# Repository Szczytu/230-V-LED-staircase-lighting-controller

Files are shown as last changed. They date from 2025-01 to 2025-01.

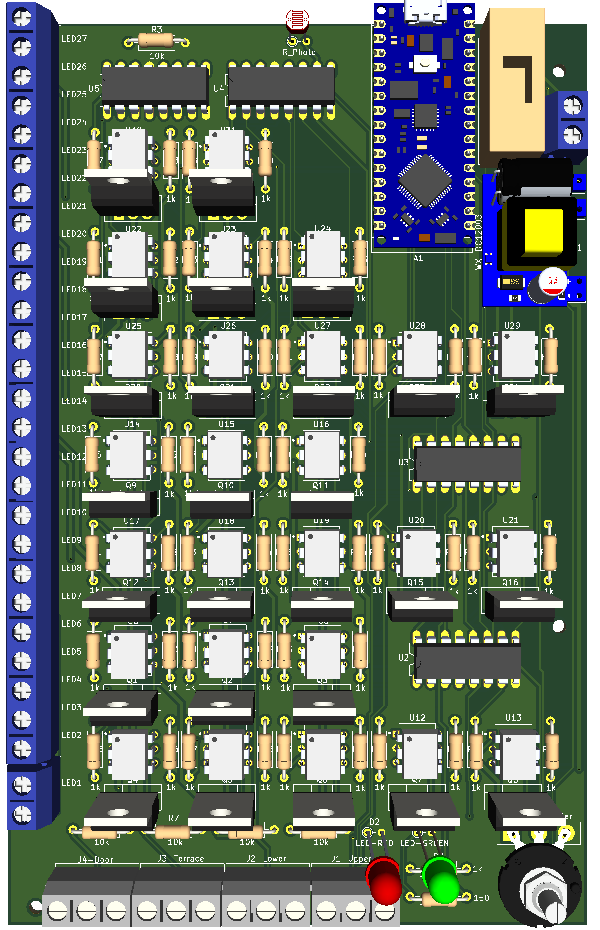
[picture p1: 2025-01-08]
PCB_162x104mm_LED_STAIRS_KiCad/CONTROLLER_LED_STAIRS_230V.png

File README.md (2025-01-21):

# 230-V-LED-staircase-lighting-controller
Controller for a large staircase consisting of 3 parts, total 26 stairs on 230 V LED strips. The controller has a built-in twilight sensor, the sensitivity of which can be adjusted using a potentiometer.
The construction of the controller was due to an unusual staircase and the desire not to use a separate power supply for 12-24V LEDs 
# Schematic and project controller of 230V LED
The project schematic, sample 3D model and gerber file is in the folder "PCB_162x104mm_LED_STAIRS"
The project was made in KiCad 8.0.
## Schematic
<p align="center">
  
</p>

## Simplified schematic
<p align="center">
  
</p>

> [!IMPORTANT]
> 1 leg of the BT136 triac is connected to the PHASE of the LED strip.
The 2nd leg of the BT136 triac is connected to the PHASE of the AC mains. The 3rd leg of the BT136 triac is connected to the gate of the power3061 controller.

> [!CAUTION]
> DO NOT SWAP THE CONNECTION FROM THE 1ST LEG WITH THE 2ND LEG OF THE BT-136 TRIAC BECAUSE IT WILL NOT WORK!

## 3D model
<p align="center">
  
  
</p>

## Final efect of the controller
A universal Kradex Z112A plastic housing with dimensions of 186x136x40mm was used to enclose the PCB
<p align="center">
  
  
  
</p>

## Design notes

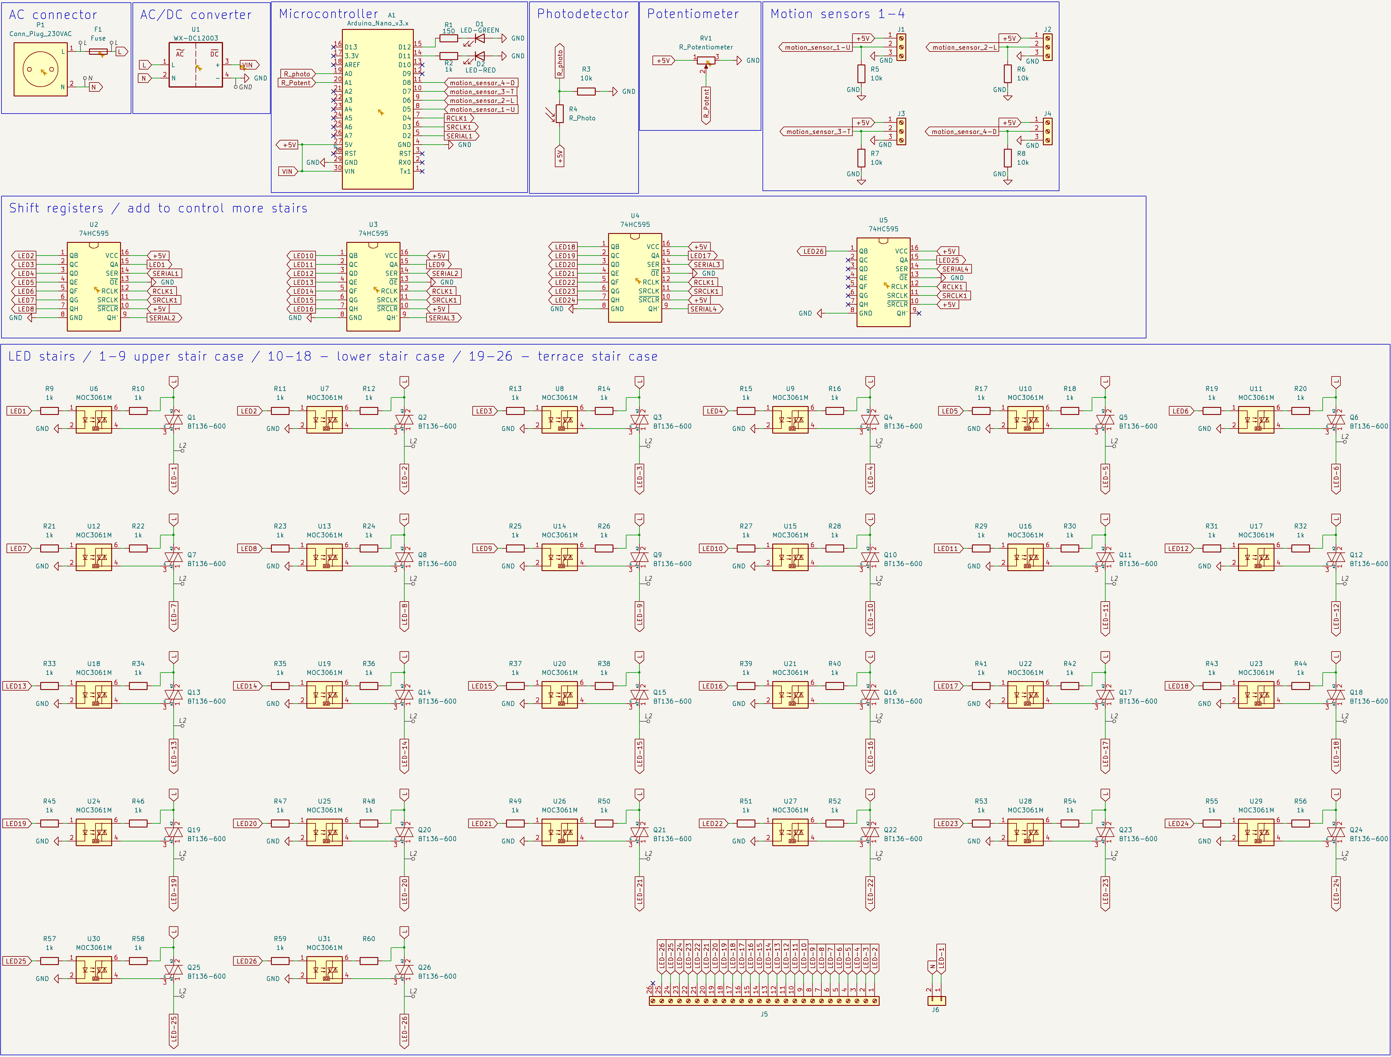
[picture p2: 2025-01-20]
PCB_162x104mm_LED_STAIRS_KiCad/CONTROLLER_LED_STAIRS_230V_schematic.png

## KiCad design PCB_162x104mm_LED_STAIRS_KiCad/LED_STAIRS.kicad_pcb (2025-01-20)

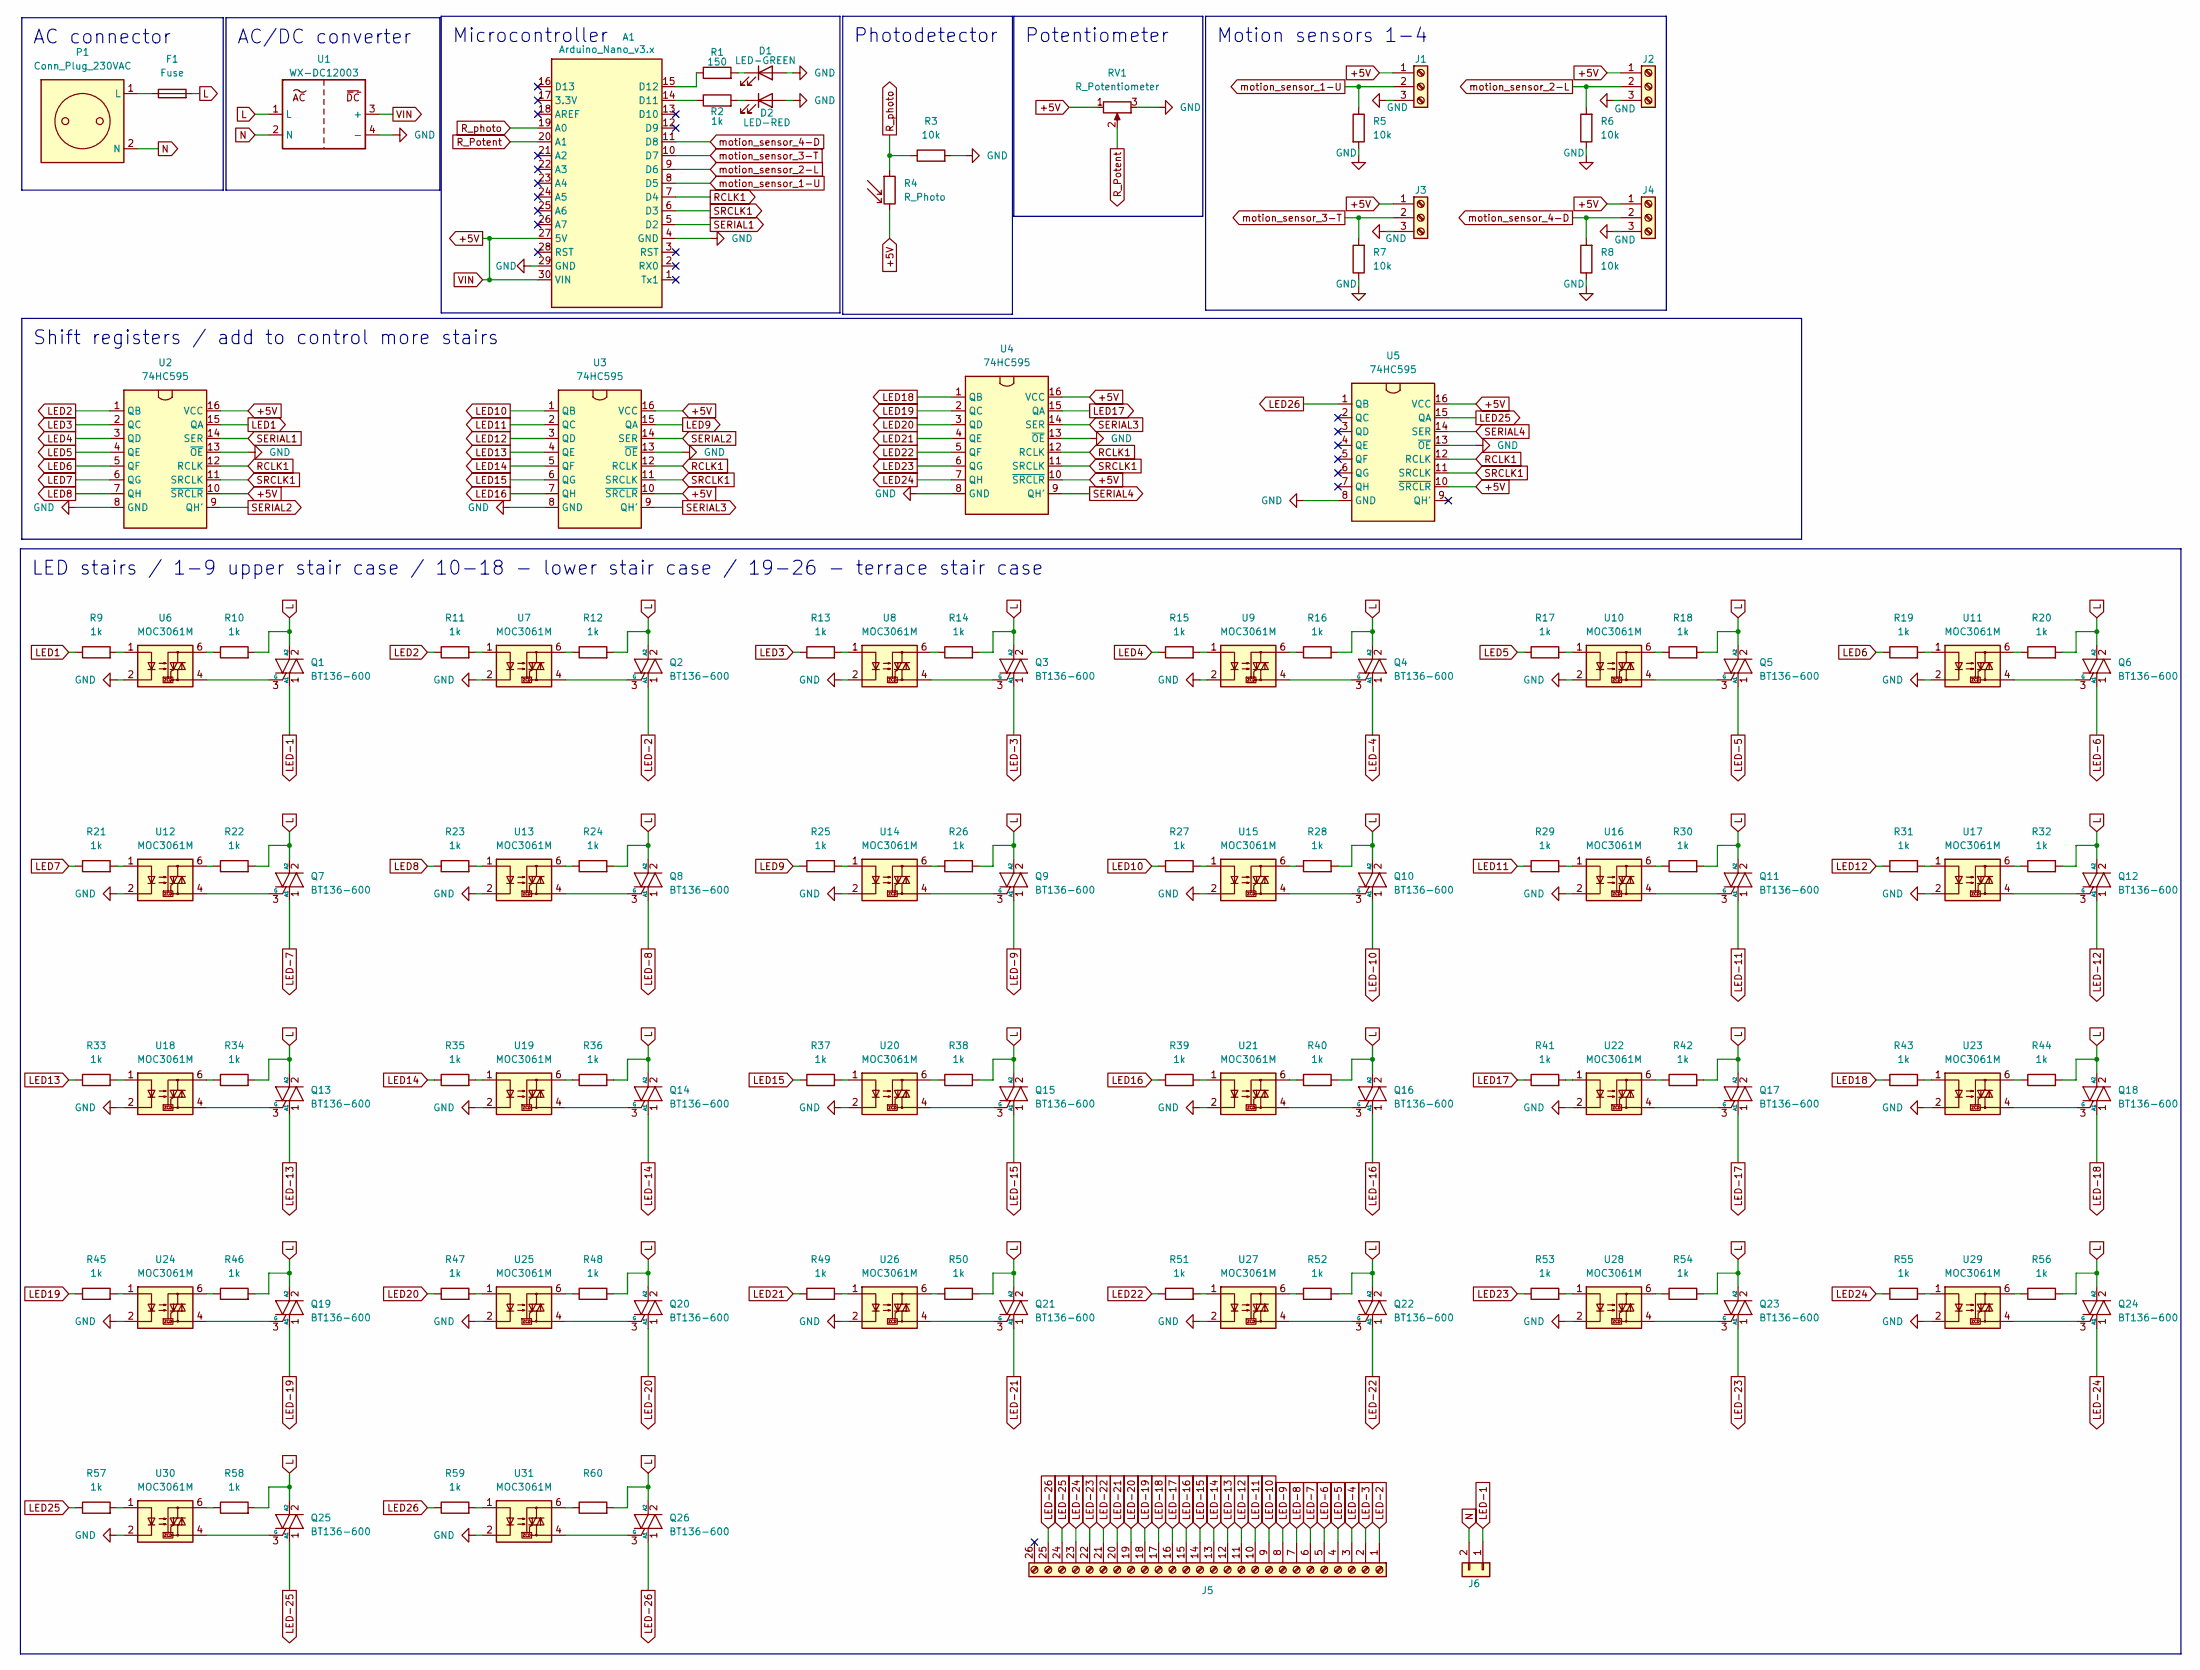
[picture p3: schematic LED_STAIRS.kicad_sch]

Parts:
A1: Arduino_Nano_v3.x; Arduino_Nano
D1: LED-GREEN; R_Axial_DIN0204_L3.6mm_D1.6mm_P2.54mm_Vertical
D2: LED-RED; R_Axial_DIN0204_L3.6mm_D1.6mm_P2.54mm_Vertical
F1: Fuse; Fuseholder_Cylinder-5x20mm_Stelvio-Kontek_PTF78_Horizontal_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
J1, J2, J3, J4: Screw_Terminal_01x03; terminalx03x2.5mmPitch
J5: Screw_Terminal_01x26; terminalx26x2.5mmPitch
J6: Conn_01x02; terminalx02x2.5mmPitch
P1: Conn_Plug_230VAC; terminalx02x2.5mmPitch
Q1, Q2, Q3, Q4, Q5, Q6, Q7, Q8, Q9, Q10, Q11, Q12, Q13, Q14, Q15, Q16, Q17, Q18, Q19, Q20, Q21, Q22, Q23, Q24, Q25, Q26: BT136-600; TO-220-3_Vertical
R1: 150; R_Axial_DIN0207_L6.3mm_D2.5mm_P10.16mm_Horizontal
R2, R9, R10, R11, R12, R13, R14, R15, R16, R17, R18, R19, R20, R21, R22, R23, R24, R25, R26, R27, R28, R29, R30, R31, R32, R33, R34, R35, R36, R37, R38, R39, R40, R41, R42, R43, R44, R45, R46, R47, R48, R49, R50, R51, R52, R53, R54, R55, R56, R57, R58, R59, R60: 1k; R_Axial_DIN0207_L6.3mm_D2.5mm_P10.16mm_Horizontal
R3, R5, R6, R7, R8: 10k; R_Axial_DIN0207_L6.3mm_D2.5mm_P10.16mm_Horizontal
R4: R_Photo; R_Axial_DIN0204_L3.6mm_D1.6mm_P2.54mm_Vertical
RV1: R_Potentiometer; Potentiometer_5k
U1: WX-DC12003
U2, U3, U4, U5: 74HC595; 74HC595N
U6, U7, U8, U9, U10, U11, U12, U13, U14, U15, U16, U17, U18, U19, U20, U21, U22, U23, U24, U25, U26, U27, U28, U29, U30, U31: MOC3061M; moc3021

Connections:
+5V: A1.27 (5V), A1.30 (VIN), J1.1, J2.1, J3.1, J4.1, R4.2, RV1.1, U1.3 (+), U2.10 (~SRCLR), U2.16 (VCC), U3.10 (~SRCLR), U3.16 (VCC), U4.10 (~SRCLR), U4.16 (VCC), U5.10 (~SRCLR), U5.16 (VCC); also elsewhere on the board
GND: A1.4 (GND), A1.29 (GND), D1.2 (A), D2.2 (A), J1.3, J2.3, J3.3, J4.3, R3.2, R5.2, R6.1, R7.1, R8.1, RV1.3, U1.4 (-), U2.8 (GND), U2.13 (~OE), U3.8 (GND), U3.13 (~OE), U4.8 (GND), U4.13 (~OE), U5.8 (GND), U5.13 (~OE), U6.2, U7.2, U8.2, U9.2, U10.2, U11.2, U12.2, U13.2, U14.2, U15.2, U16.2, U17.2, U18.2, U19.2, U20.2, U21.2, U22.2, U23.2, U24.2, U25.2, U26.2, U27.2, U28.2, U29.2, U30.2, U31.2; also elsewhere on the board
L: F1.2, Q1.2 (A2), Q2.2 (A2), Q3.2 (A2), Q4.2 (A2), Q5.2 (A2), Q6.2 (A2), Q7.2 (A2), Q8.2 (A2), Q9.2 (A2), Q10.2 (A2), Q11.2 (A2), Q12.2 (A2), Q13.2 (A2), Q14.2 (A2), Q15.2 (A2), Q16.2 (A2), Q17.2 (A2), Q18.2 (A2), Q19.2 (A2), Q20.2 (A2), Q21.2 (A2), Q22.2 (A2), Q23.2 (A2), Q24.2 (A2), Q25.2 (A2), Q26.2 (A2), R10.2, R12.2, R14.2, R16.2, R18.2, R20.2, R22.2, R24.2, R26.2, R28.2, R30.2, R32.2, R34.2, R36.2, R38.2, R40.2, R42.2, R44.2, R46.2, R48.2, R50.2, R52.2, R54.2, R56.2, R58.2, R60.2, U1.1 (L)
LED1: R9.1, U2.15 (QA)
LED2: R11.1, U2.1 (QB)
LED3: R13.1, U2.2 (QC)
LED4: R15.1, U2.3 (QD)
LED5: R17.1, U2.4 (QE)
LED6: R19.1, U2.5 (QF)
LED7: R21.1, U2.6 (QG)
LED8: R23.1, U2.7 (QH)
LED9: R25.1, U3.15 (QA)
LED10: R27.1, U3.1 (QB)
LED11: R29.1, U3.2 (QC)
LED12: R31.1, U3.3 (QD)
LED13: R33.1, U3.4 (QE)
LED14: R35.1, U3.5 (QF)
LED15: R37.1, U3.6 (QG)
LED16: R39.1, U3.7 (QH)
LED17: R41.1, U4.15 (QA)
LED18: R43.1, U4.1 (QB)
LED19: R45.1, U4.2 (QC)
LED20: R47.1, U4.3 (QD)
LED21: R49.1, U4.4 (QE)
LED22: R51.1, U4.5 (QF)
LED23: R53.1, U4.6 (QG)
LED24: R55.1, U4.7 (QH)
LED25: R57.1, U5.15 (QA)
LED26: R59.1, U5.1 (QB)
LED-1: J6.1, Q1.1 (A1)
LED-2: J5.1, Q2.1 (A1)
LED-3: J5.2, Q3.1 (A1)
LED-4: J5.3, Q4.1 (A1)
LED-5: J5.4, Q5.1 (A1)
LED-6: J5.5, Q6.1 (A1)
LED-7: J5.6, Q7.1 (A1)
LED-8: J5.7, Q8.1 (A1)
LED-9: J5.8, Q9.1 (A1)
LED-10: J5.9, Q10.1 (A1)
LED-11: J5.10, Q11.1 (A1)
LED-12: J5.11, Q12.1 (A1)
LED-13: J5.12, Q13.1 (A1)
LED-14: J5.13, Q14.1 (A1)
LED-15: J5.14, Q15.1 (A1)
LED-16: J5.15, Q16.1 (A1)
LED-17: J5.16, Q17.1 (A1)
LED-18: J5.17, Q18.1 (A1)
LED-19: J5.18, Q19.1 (A1)
LED-20: J5.19, Q20.1 (A1)
LED-21: J5.20, Q21.1 (A1)
LED-22: J5.21, Q22.1 (A1)
LED-23: J5.22, Q23.1 (A1)
LED-24: J5.23, Q24.1 (A1)
LED-25: J5.24, Q25.1 (A1)
LED-26: J5.25, Q26.1 (A1)
N: J6.2, P1.2 (N), U1.2 (N); also elsewhere on the board
unnamed: A1.14 (D11), R2.1
unnamed: A1.15 (D12), R1.1
unnamed: D1.1 (K), R1.2
unnamed: D2.1 (K), R2.2
unnamed 60: F1.1, P1.1 (L); also elsewhere on the board
unnamed: Q1.3 (G), U6.4
unnamed: Q2.3 (G), U7.4
unnamed: Q3.3 (G), U8.4
unnamed: Q4.3 (G), U9.4
unnamed: Q5.3 (G), U10.4
unnamed: Q6.3 (G), U11.4
unnamed: Q7.3 (G), U12.4
unnamed: Q8.3 (G), U13.4
unnamed: Q9.3 (G), U14.4
unnamed: Q10.3 (G), U15.4
unnamed: Q11.3 (G), U16.4
unnamed: Q12.3 (G), U17.4
unnamed: Q13.3 (G), U18.4
unnamed: Q14.3 (G), U19.4
unnamed: Q15.3 (G), U20.4
unnamed: Q16.3 (G), U21.4
unnamed: Q17.3 (G), U22.4
unnamed: Q18.3 (G), U23.4
unnamed: Q19.3 (G), U24.4
unnamed: Q20.3 (G), U25.4
unnamed: Q21.3 (G), U26.4
unnamed: Q22.3 (G), U27.4
unnamed: Q23.3 (G), U28.4
unnamed: Q24.3 (G), U29.4
unnamed: Q25.3 (G), U30.4
unnamed: Q26.3 (G), U31.4
unnamed: R9.2, U6.1
unnamed: R10.1, U6.6
unnamed: R11.2, U7.1
unnamed: R12.1, U7.6
unnamed: R13.2, U8.1
unnamed: R14.1, U8.6
unnamed: R15.2, U9.1
unnamed: R16.1, U9.6
unnamed: R17.2, U10.1
unnamed: R18.1, U10.6
unnamed: R19.2, U11.1
unnamed: R20.1, U11.6
unnamed: R21.2, U12.1
unnamed: R22.1, U12.6
unnamed: R23.2, U13.1
unnamed: R24.1, U13.6
unnamed: R25.2, U14.1
unnamed: R26.1, U14.6
unnamed: R27.2, U15.1
unnamed: R28.1, U15.6
unnamed: R29.2, U16.1
unnamed: R30.1, U16.6
unnamed: R31.2, U17.1
unnamed: R32.1, U17.6
unnamed: R33.2, U18.1
unnamed: R34.1, U18.6
unnamed: R35.2, U19.1
unnamed: R36.1, U19.6
unnamed: R37.2, U20.1
unnamed: R38.1, U20.6
unnamed: R39.2, U21.1
unnamed: R40.1, U21.6
unnamed: R41.2, U22.1
unnamed: R42.1, U22.6
unnamed: R43.2, U23.1
unnamed: R44.1, U23.6
unnamed: R45.2, U24.1
unnamed: R46.1, U24.6
unnamed: R47.2, U25.1
unnamed: R48.1, U25.6
unnamed: R49.2, U26.1
unnamed: R50.1, U26.6
unnamed: R51.2, U27.1
unnamed: R52.1, U27.6
unnamed: R53.2, U28.1
unnamed: R54.1, U28.6
unnamed: R55.2, U29.1
unnamed: R56.1, U29.6
unnamed: R57.2, U30.1
unnamed: R58.1, U30.6
unnamed: R59.2, U31.1
unnamed: R60.1, U31.6
RCLK1: A1.7 (D4), U2.12 (RCLK), U3.12 (RCLK), U4.12 (RCLK), U5.12 (RCLK)
R_Potent: A1.20 (A1), RV1.2; also elsewhere on the board
R_photo: A1.19 (A0), R3.1, R4.1
SERIAL1: A1.5 (D2), U2.14 (SER)
SERIAL2: U2.9 (QH'), U3.14 (SER)
SERIAL3: U3.9 (QH'), U4.14 (SER)
SERIAL4: U4.9 (QH'), U5.14 (SER)
SRCLK1: A1.6 (D3), U2.11 (SRCLK), U3.11 (SRCLK), U4.11 (SRCLK), U5.11 (SRCLK)
motion_sensor_1-U: A1.8 (D5), J1.2, R5.1; also elsewhere on the board
motion_sensor_2-L: A1.9 (D6), J2.2, R6.2; also elsewhere on the board
motion_sensor_3-T: A1.10 (D7), J3.2, R7.2; also elsewhere on the board
motion_sensor_4-D: A1.11 (D8), J4.2, R8.2; also elsewhere on the board

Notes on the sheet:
Potentiometer
AC connector
LED stairs / 1-9 upper stair case / 10-18 - lower stair case / 19-26 - terrace stair case
AC/DC converter
Microcontroller
Motion sensors 1-4
Shift registers / add to control more stairs
Photodetector

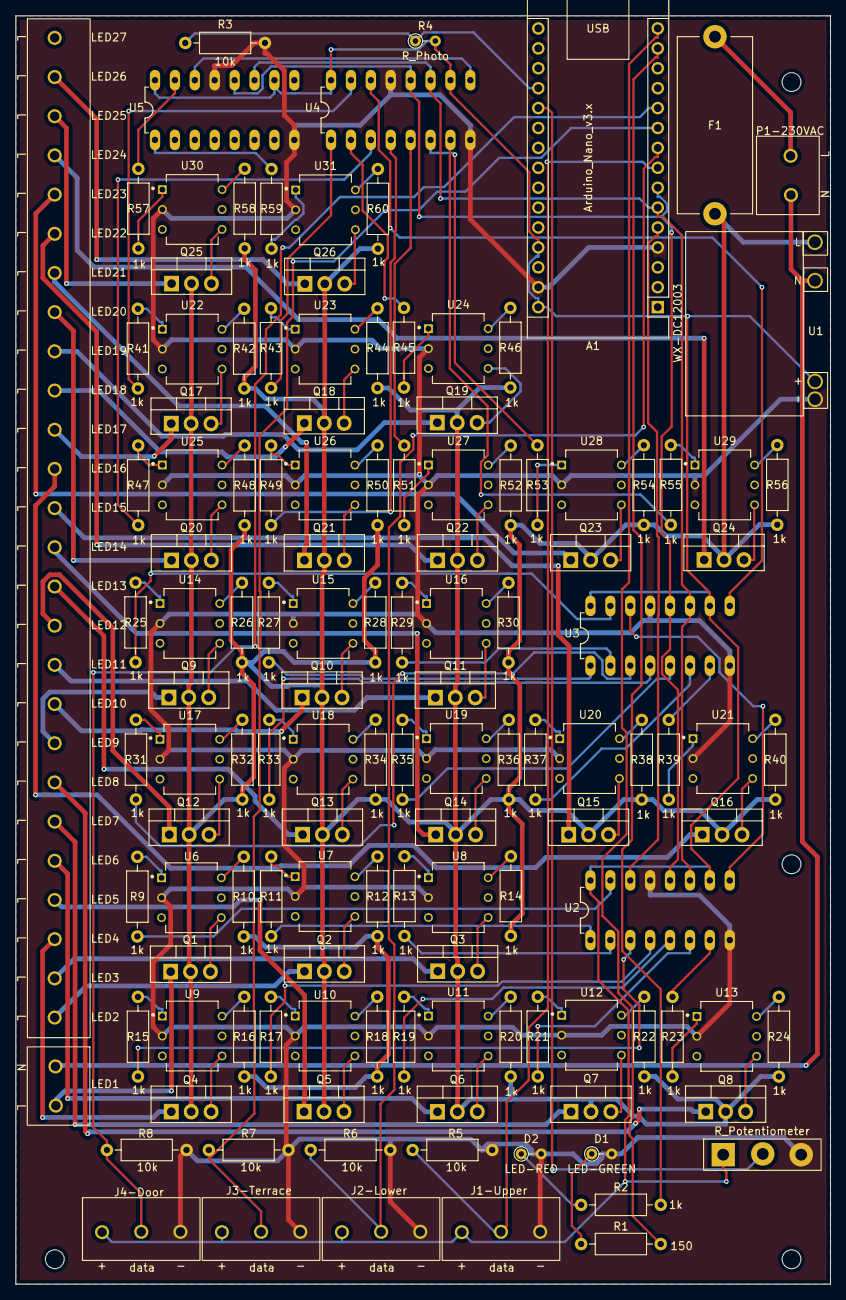
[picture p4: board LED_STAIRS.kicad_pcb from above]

Board: 2 copper layers, 103.9 x 161.8 mm, 129 parts (0 on the bottom side), 151 nets.

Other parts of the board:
J1-Upper, J2-Lower, J3-Terrace, J4-Door: Screw_Terminal_01x03; terminalx03x2.5mmPitch
P1-230VAC: Conn_Plug_230VAC; terminalx02x2.5mmPitch
R_Potentiometer: R_Potentiometer; Potentiometer_5k

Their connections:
+5V: J1-Upper.1, J2-Lower.1, J3-Terrace.1, J4-Door.1, R_Potentiometer.1; also elsewhere on the board
GND: J1-Upper.3, J2-Lower.3, J3-Terrace.3, J4-Door.3, R_Potentiometer.3; also elsewhere on the board
N: P1-230VAC.2 (N); also elsewhere on the board
unnamed 60: P1-230VAC.1 (L); also elsewhere on the board
R_Potent: R_Potentiometer.2; also elsewhere on the board
motion_sensor_1-U: J1-Upper.2; also elsewhere on the board
motion_sensor_2-L: J2-Lower.2; also elsewhere on the board
motion_sensor_3-T: J3-Terrace.2; also elsewhere on the board
motion_sensor_4-D: J4-Door.2; also elsewhere on the board

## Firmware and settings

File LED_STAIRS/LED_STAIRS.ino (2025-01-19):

const int dataPin = 2;   // D2 - A (Data)
const int clockPin = 3;  // D3 - SHIFT_CLK (Clock)
const int latchPin = 4;  // D4 - LATCH_CLK (Latch)
int photoresistor = A0;
int potenciometr = A1;
// Tablica przechowująca stan LED-ów (4 rejestry dla 26 diod)
byte leds[4] = {0};

unsigned long lastMovementTime = 0;  // Ostatni czas wykrycia ruchu
const unsigned long timeout = 30000; // 30 sekund
bool isExecuting = false;            // Czy sekwencja jest w trakcie
int activeSequence = -1;             // -1 = brak, 0 = góra, 1 = dół, 2 = taras, 3 = drzwi wejściowe


// Funkcja zapalania diod dla górnej klatki
void TriggerON_Upper_staircase() {
  for (int i = 0; i <= 8; i++) {
    setLed(i, HIGH);
    delay(500);
  }
  for (int x = 9, y = 18; x <= 17 || y <= 25; x++, y++) {
    setLed(x, HIGH);
    setLed(y, HIGH);
    delay(500);
  }
}

// Funkcja zapalania diod dla dolnej klatki
void TriggerON_Lower_staircase() {
  for (int i = 17; i >= 9; i--) {
    setLed(i, HIGH);
    Serial.print("Zapalam LED: ");
    Serial.println(i);
    delay(500);
  }
  for (int x = 8, y = 18; x >= 0 || y <= 25; x--, y++) {
    setLed(x, HIGH);
    setLed(y, HIGH);
    Serial.print("Zapalam LED: ");
    Serial.print(x);
    Serial.print(" i LED: ");
    Serial.println(y);
    delay(500);
  }
}


// Funkcja zapalania diod od tarasu
void TriggerON_Terrace() {
  for (int i = 25; i >= 18; i--) {
    setLed(i, HIGH);
    delay(500);
  }
  for (int x = 8, y = 9; x >= 0 || y <= 17; x--, y++) {
    setLed(x, HIGH);
    setLed(y, HIGH);
    delay(500);
  }

}

// Funkcja zapalania diod na schodach tylko na tarasie
void TriggerON_entrance_door() {
  for (int i = 25; i >= 18; i--) {
    setLed(i, HIGH);
  }
}

// Funkcja obsługi diod (zapalenie lub zgaszenie)
void setLed(int led, bool state) {
  int reg = led / 8;       // Który rejestr (0, 1, 2, 3)
  int bit = led % 8;       // Który bit w rejestrze
  bitWrite(leds[reg], bit, state);
  updateShiftRegisters();
}

void updateShiftRegisters() {
  digitalWrite(latchPin, LOW);
  for (int i = 3; i >= 0; i--) {
    shiftOut(dataPin, clockPin, MSBFIRST, leds[i]);
  }
  digitalWrite(latchPin, HIGH);
}

// Zgaszenie wszystkich diod
void clearAllLeds() {
  for (int i = 0; i < 4; i++) {
    leds[i] = 0;
  }
  updateShiftRegisters();
}




//******************SETUP******************

void setup() {
  Serial.begin(115200);
  // Czujniki ruchu
  pinMode(5, INPUT); // czujnik klatka góra
  pinMode(6, INPUT); // czujnik klatka dół
  pinMode(7, INPUT); // czujnik taras
  pinMode(8, INPUT); // czujnik dodatkowy drzwi wejściowe
  pinMode(5, LOW); // czujnik klatka góra
  pinMode(6, LOW); // czujnik klatka dół
  pinMode(7, LOW); // czujnik taras
  pinMode(8, LOW);
  // Rejestr przesuwny
  pinMode(dataPin, OUTPUT);
  pinMode(clockPin, OUTPUT);
  pinMode(latchPin, OUTPUT);
  // Diody sygnalizujące czy LEDy się zaświecą
  pinMode(11, OUTPUT); // czerwony LED
  pinMode(12, OUTPUT); // zielony LED
  digitalWrite(11, LOW);
  digitalWrite(12, LOW);
  // Zgaszenie wszystkich diod
  clearAllLeds();
}




//******************MAIN PROGRAM******************

void loop() {
  photoresistor = analogRead(A0);
  photoresistor = map(photoresistor, 0 , 1023, 0 , 100);
  Serial.print("Poziom ciemnosci:");
  Serial.println(photoresistor);
  potenciometr = analogRead(A1);
  //Serial.println(potenciometr);
  //delay(300);
  
  int sensitivity = map(potenciometr, 0, 1023, 0, 100); //1023
  Serial.print("ustawiony poziom czułości na światło:");
  Serial.println(sensitivity);
  if (photoresistor  < sensitivity) {
    // Zasygnalizuj odpowiednie ustawienie czułości na poziom światła sterownika
    digitalWrite(11, LOW);
    digitalWrite(12, HIGH);
    Serial.print("Czerwony LED ");
    Serial.println(digitalRead(11));
    Serial.print("Zielony LED ");
    Serial.println(digitalRead(12));
    // Sprawdź, który czujnik wykrył ruch
    bool upperTriggered = digitalRead(5) == HIGH;
    bool lowerTriggered = digitalRead(6) == HIGH;
    bool terraceTriggered = digitalRead(7) == HIGH;
    bool entrance_doorTriggered = digitalRead(8) == HIGH;

    if (!isExecuting) {
      // Zidentyfikuj pierwszy ruch i rozpocznij odpowiednią sekwencję
      if (upperTriggered) {
        Serial.println("Ruch na górze");
        isExecuting = true;
        activeSequence = 0;
        lastMovementTime = millis();  // Aktualizuj czas ostatniego ruchu
        TriggerON_Upper_staircase();
        isExecuting = false;
      } 
      else if (lowerTriggered) {
        Serial.println("Ruch na dole");
        isExecuting = true;
        activeSequence = 1;
        lastMovementTime = millis();  // Aktualizuj czas ostatniego ruchu
        TriggerON_Lower_staircase();
        isExecuting = false;
      } 
      else if (terraceTriggered) {
        Serial.println("Ruch na schodach na tarasie");
        isExecuting = true;
        activeSequence = 2;
        lastMovementTime = millis();  // Aktualizuj czas ostatniego ruchu
        TriggerON_Terrace();
        isExecuting = false;
      } 
      else if (entrance_doorTriggered) {
        Serial.println("Ruch na drzwiach wejściowych");
        isExecuting = true;
        activeSequence = 3;
        lastMovementTime = millis();  // Aktualizuj czas ostatniego ruchu
        TriggerON_entrance_door();
        isExecuting = false;
     }
    
    }
  

    // Po zakończeniu sekwencji monitoruj czujniki
    if (activeSequence != -1) {
      if (upperTriggered || lowerTriggered || terraceTriggered || entrance_doorTriggered) {
         lastMovementTime = millis(); // Aktualizacja czasu przy każdym ruchu
         Serial.println("Ruch wykryty - resetowanie odliczania czasu.");
      }

    // Oblicz czas pozostały do zgaszenia LED
    double elapsedTime = millis() - lastMovementTime;
    if (elapsedTime < timeout) {
      double remainingTime = timeout - elapsedTime;
      Serial.print("Pozostały czas do zgaśnięcia LED: ");
      Serial.print(remainingTime / 1000); // Wyświetl w sekundach
      Serial.println(" s");
      }
    }

    // Jeśli brak ruchu przez określony czas, zgaś wszystkie diody
    if (millis() - lastMovementTime > timeout) {
      Serial.println("Brak ruchu - gaszę wszystkie diody.");
      clearAllLeds();
      activeSequence = -1; // Reset aktywnej sekwencji
      }

  }
  else{
    Serial.println("Jasno na klatce");
    digitalWrite(11, HIGH); //czerwone
    digitalWrite(12, LOW); //zielone
    Serial.print("czerwony LED ");
    Serial.println(digitalRead(11)); //czerwone
    Serial.print("Zielony LED ");
    Serial.println(digitalRead(12), "zielone"); //zielone
    clearAllLeds();
    activeSequence = -1; // Reset aktywnej sekwencji
  }

}
